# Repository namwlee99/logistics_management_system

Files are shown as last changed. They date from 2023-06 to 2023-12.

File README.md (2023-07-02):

# 물류관리 시스템
## 작품소개
이 작품은 물류관리 시스템으로, Raspberry Pi 프로세서를 기반으로 개발되었습니다. 시스템은 PI 카메라, 컨베이어 벨트, IR Sensor, Servo Motor 등을 효과적으로 활용하여 물류 작업을 자동화합니다. 또한 화재 감지 센서와 물 감지 센서를 통해 창고를 효율적으로 관리할 수 있습니다. LCD와 Buzzer를 사용하여 창고의 상태를 실시간으로 확인할 수 있습니다. 이 시스템은 물류 작업 환경에서 보다 효율적인 창고 관리를 지원하며, 사고나 이상 상황을 신속하게 감지하여 조치할 수 있도록 도와줍니다. 더욱 정확하고 안전한 물류 운영을 위해 다양한 기능을 통합하여 최적의 창고 관리 솔루션을 제공합니다.

## 팀구성
아이디어 제안 및 기획: **이남웅**   
하드웨어 설계 및 구현: 정승훈   
소프트웨어 개발: **이남웅**   
디자인: 정승훈   
시스템 통합 및 테스트: **이남웅**   

## 개발기간
2022/06/24 ~ 2022/09/28

## 사용한 부품
PI 카메라: QR 코드를 식별하여 인식할 수 있는 카메라입니다. 이를 통해 물류 작업에서 중요한 정보를 자동으로 인식하고 처리할 수 있습니다.

DHT11 센서: 창고의 온도와 습도를 측정하는 센서입니다. 스토리지의 적절한 환경을 유지하기 위해 사용됩니다.

Water Sensor: 물이 센서에 닿으면 작동하는 센서입니다. 누수나 수위 변화를 신속하게 감지하여 관련 문제를 예방하거나 조치할 수 있습니다.

Gas Sensor: 가스가 근처에 발생할 경우 작동하는 센서입니다. 유해 가스 누출을 신속하게 감지하여 안전에 기여합니다.

Flame Sensor: 불이 근처에 있을 경우 작동하는 센서입니다. 화재를 조기에 감지하고 경보를 울리거나 조치를 취할 수 있습니다.

Buzzer: 재난 감지 센서가 작동할 경우 경보를 발생시키는 소리 알림 장치입니다.

LCD2004: 스토리지의 적재량, 온습도 등의 정보를 표시하는 20x4 문자 LCD입니다. 또한 재난 상황 발생 시 경고 메시지를 표시하여 시각적으로 알릴 수 있습니다.

TT Motor: 컨베이어 벨트를 조작하기 위해 양 끝단에 설치된 모터입니다. 스토리지 내 물체를 분류하고 이동시키는 역할을 합니다.

MCP3008: 아날로그 신호를 디지털 신호로 변환해주는 ADC(Analog-to-Digital Converter) 칩입니다. Water Sensor와 같이 아날로그 입력을 받아서 Raspberry Pi가 처리할 수 있는 디지털 신호로 변환합니다.

IR Sensor: 컨베이어 벨트 위에 있는 물체를 감지하는 인프라레드(IR) 센서입니다. 물체의 존재를 신속하게 감지하여 작업 프로세스를 제어하거나 인식에 활용할 수 있습니다.

Servo Motor: 스토리지 내 물체를 분류하기 위해 사용되는 모터입니다. 스토리지 별로 물체를 이동시키거나 배치할 수 있습니다.   

## 동작방식
### PI 카메라를 통한 바코드 인식
1. PI 카메라는 제품에 있는 바코드를 인식하여 위치 정보를 가져옵니다. 이 정보를 기반으로 해당 제품이 위치한 컨베이어 벨트가 작동하게 됩니다. 만약 PI 카메라가 바코드를 인식하지 못할 경우 Buzzer가 작동하여 경고음을 울립니다.

2. IR 센서를 통한 위치 인식: 제품이 교차점에 도달하면 교차점에 있는 IR 센서가 제품의 위치를 감지하여 인식합니다. 이를 통해 제품을 이동시킬지 여부를 판별합니다.

3. 서브모터를 이용한 제품 이동: 해당 교차점에서 제품을 이동해야 할 경우, 서브모터가 작동하여 제품을 원하는 위치로 이동시킵니다. 이를 통해 제품의 효율적인 관리와 분류가 가능해집니다.

### 센서 내장 및 상태 확인
시스템은 Flame 센서, Gas 센서, Water 센서, 온습도 센서 등을 내장하여 제품의 안전 및 환경 상태를 모니터링합니다. LCD와 Buzzer를 통해 물류창고의 상태를 실시간으로 확인할 수 있습니다.

물류관리 시스템은 PI 카메라를 통해 바코드 인식과 위치 정보를 활용하고, IR 센서와 서브모터를 이용하여 제품의 이동을 제어합니다. 또한 센서를 통해 환경 및 안전 상태를 모니터링하며, LCD와 Buzzer를 통해 사용자에게 정보를 제공합니다.

## 블록도


## 회로도
KakaoTalk_Photo_2023-07-02-10-03-41

## 사진
KakaoTalk_Photo_2023-06-25-16-47-12

## 작동 동영상
Watch the video (https://youtu.be/YHekVKBjydo)

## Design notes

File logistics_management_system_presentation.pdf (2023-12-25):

# 종합설계작품계획서

# 학 번 | 이 름 20191629 | 정승훈 20191633 | 이남웅

# 작품명 : 물류관리 시스템 4차 발표

목차

# 1. 작품개요 2. 업무분담 3. 진행일정표 4. 동작설명서(블록도/순서도) 5. 회로도 6. 프로그램 소스코드 7. 작품 동작 영상 8. 작품 활용 방안

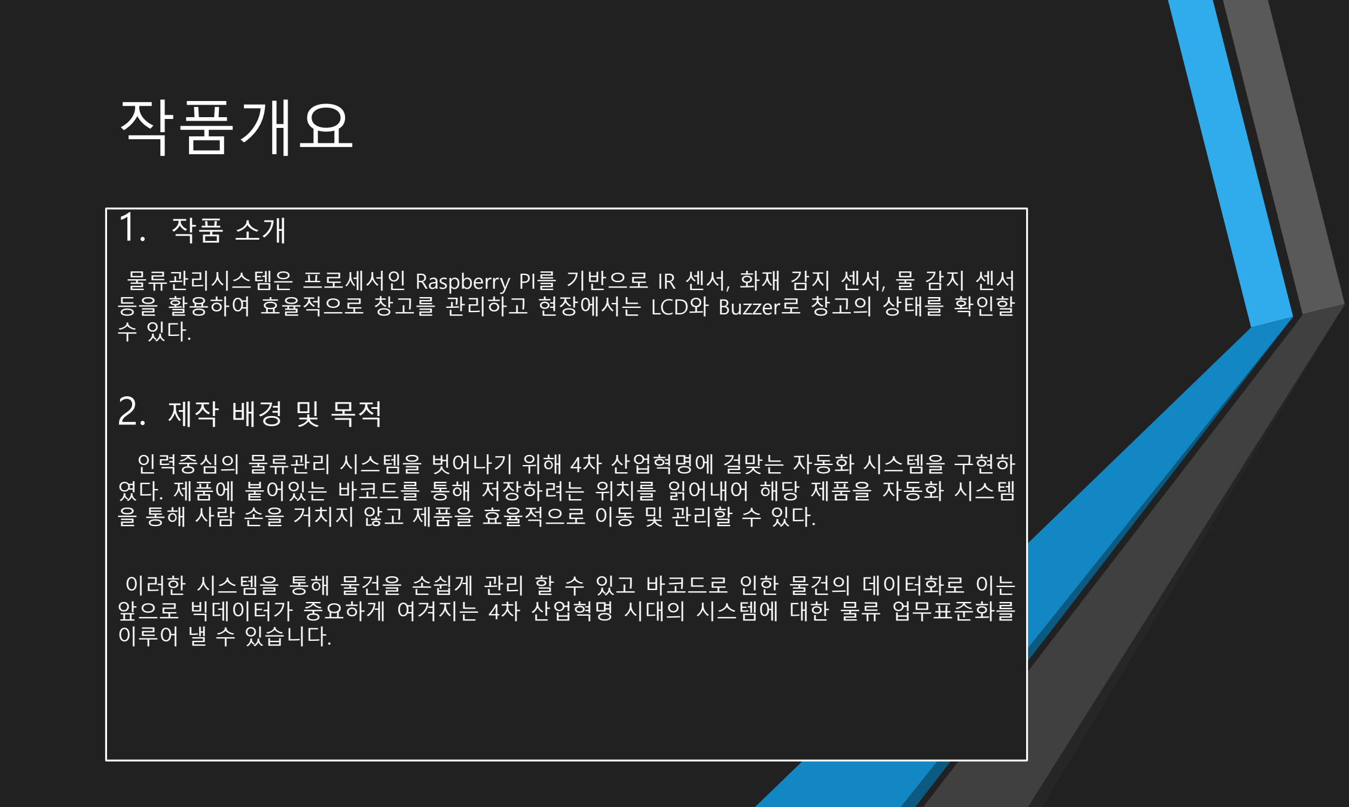
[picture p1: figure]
작품개요; 이루어 낼 수 있습니다.

# 물류관리시스템은 프로세서인 Raspberry PI를 기반으로 IR 센서, 화재 감지 센서, 물 감지 센서 등을 활용하여 효율적으로 창고를 관리하고 현장에서는 LCD와 Buzzer로 창고의 상태를 확인할

# 인력중심의 물류관리 시스템을 벗어나기 위해 4차 산업혁명에 걸맞는 자동화 시스템을 구현하 였다. 제품에 붙어있는 바코드를 통해 저장하려는 위치를 읽어내어 해당 제품을 자동화 시스템

을 통해 사람 손을 거치지 않고 제품을 효율적으로 이동 및 관리할 수 있다.

# 이러한 시스템을 통해 물건을 손쉽게 관리 할 수 있고 바코드로 인한 물건의 데이터화로 이는 앞으로 빅데이터가 중요하게 여겨지는 4차 산업혁명 시대의 시스템에 대한 물류 업무표준화를

# 업무 분담

업 무 | 담 당 자
자료수집 | 정승훈, 이남웅
도면작성 | 정승훈
자재구입 | 정승훈, 이남웅
PCB조립 | 정승훈
프로그램 작성 | 이남웅
기구부 제작 | 정승훈, 이남웅
작품연동검사 | 정승훈, 이남웅

H/W

# 정승훈

# 기구부

공동

S/W

# 이남웅

| 6 월 | 7 월 | 8 월 | 9 월
5 | 1 | 2 | 3 | 4 | 1 | 2 | 3 | 4 | 5 | 1 | 2
자료수집 | 계획
| 실적
하드웨어 구성 | 계획
| 실적
프로그래밍 | 계획
| 실적
기구물 제작 | 계획
| 실적
동작테스트 | 계획
| 실적
발표(1 차, 2 차, 3 차, 최 종 ) | 계획 | 1 차 | | | 2 차 | | | | | | 3 차 | 4 차 | 최종
| 실적
최종보고서 | 계획
| 실적
계획 | 실적

# 진행일정표

# 동작설명서

# - 물류관리 시스템은 Pi 카메라를 통해 제품에 있는 바코드를 읽어

위치정보를 불러들여 제품이 있는 컨베이어 벨트가 작동하게 되고,

# 제품이 교차점에 도달하게 되면 교차점에 있는 IR 센서가 제품 위치 를 인식하게 되고 제품을 이동시킬지 판별한다. Pi 카메라에서 바코

드 인식을 못할 경우 Buzzer가 작동하여 경적음을 울린다.

# - 만약 해당 교차점에서 이동하려고 하면 서브모터가 제품을 이동시 키게 되고, 컨베이어 벨트에서 지정된 위치로 이동시키게 된다. 제품 의 효율적 관리를 위해 Flame 센서와 Gas 센서, Water 센서, 온습도 센서를 내장하게 되고 LCD 와 Buzzer를 통해 물류창고 상태를 확인

할 수 있다.

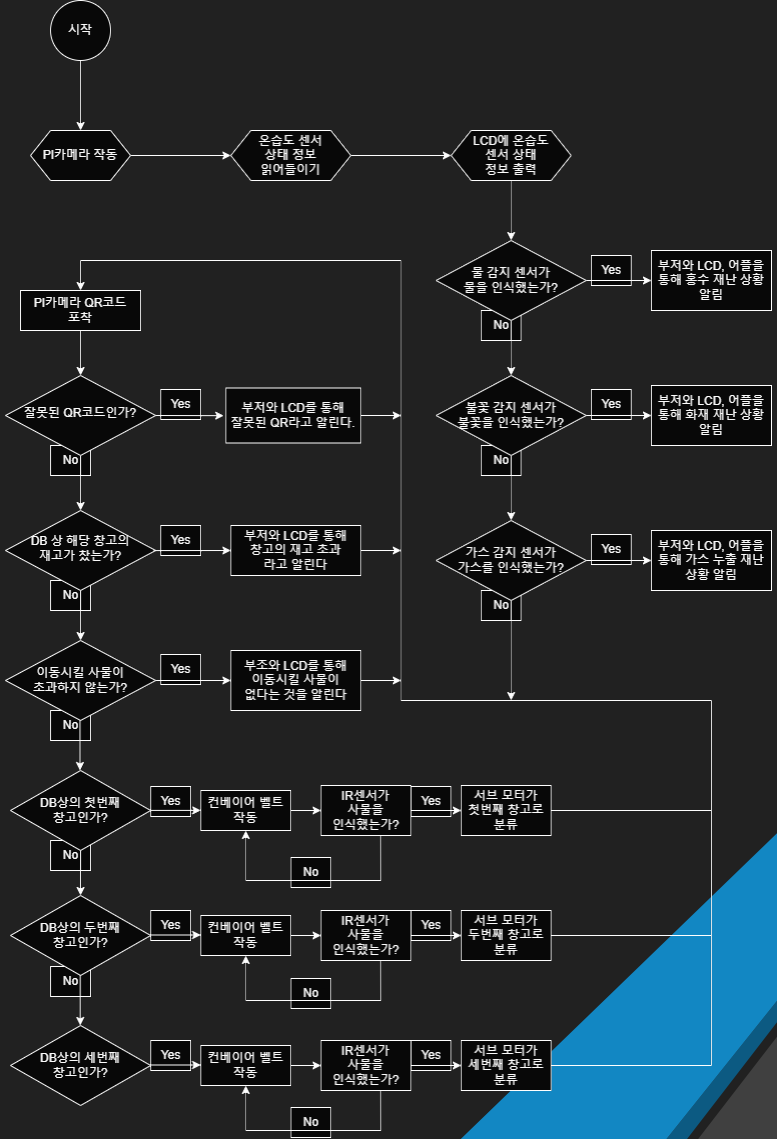
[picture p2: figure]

# 동작설명서

# - 순서도

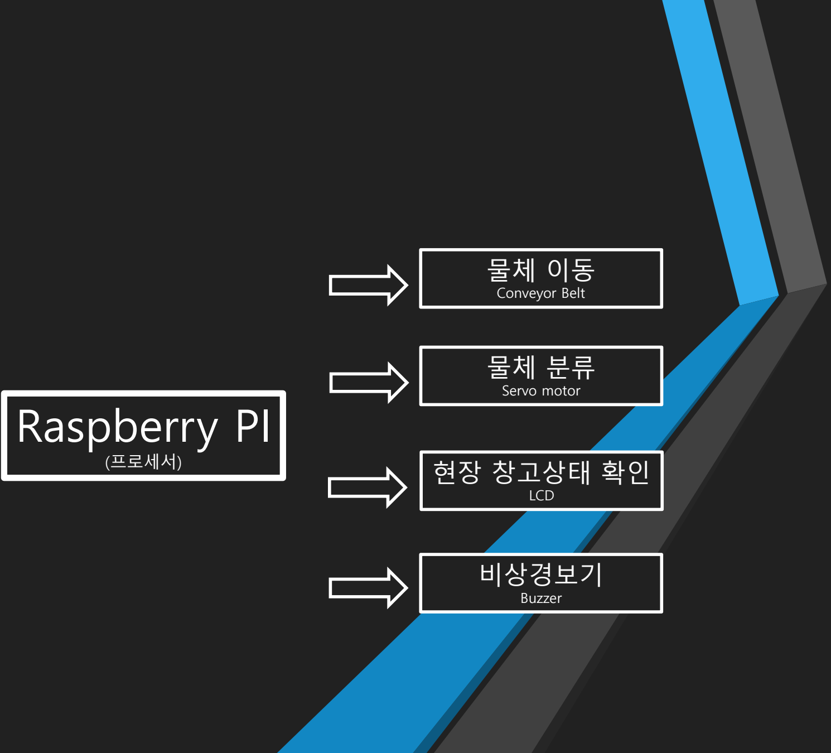
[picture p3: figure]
Conveyor Belt; Servo motor; 현장 창고상태 확인; LCD; 비상경보기; Buzzer; Raspberry PI; (프로세서)

# 동작설명서

# - 블록도

# 파이 카메라

## (바코드 인식)

# IR 센서

## (물체 인식)

# Flame 센서

## (화재감지기)

# Water 센서

## (침수감지기)

# DHT 11

## (온습도 감지기)

# 회로도

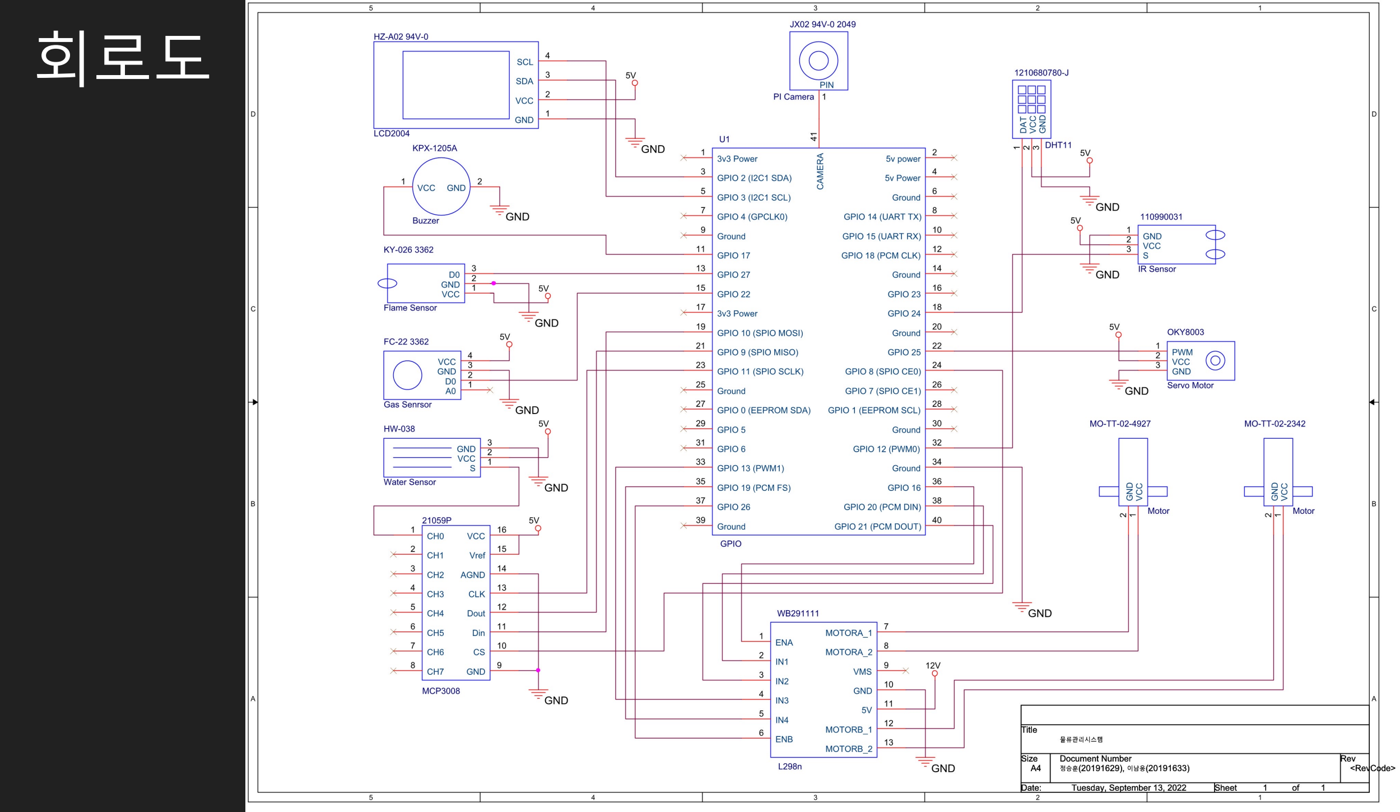
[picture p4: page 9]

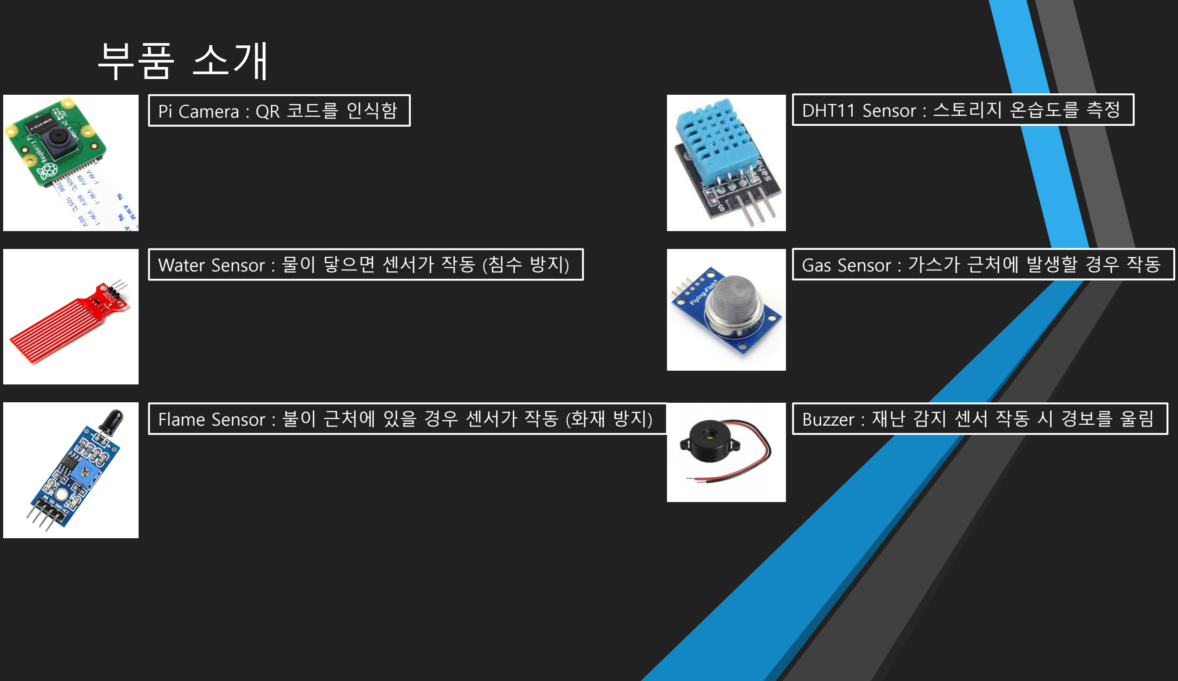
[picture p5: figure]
Pi Camera : QR 코드를 인식함; Water Sensor : 물이 닿으면 센서가 작동 (침수 방지); DHT11 Sensor : 스토리지 온습도를 측정; Gas Sensor : 가스가 근처에 발생할 경우 작동; Buzzer : 재난 감지 센서 작동 시 경보를 울림

# Flame Sensor : 불이 근처에 있을 경우 센서가 작동 (화재 방지)

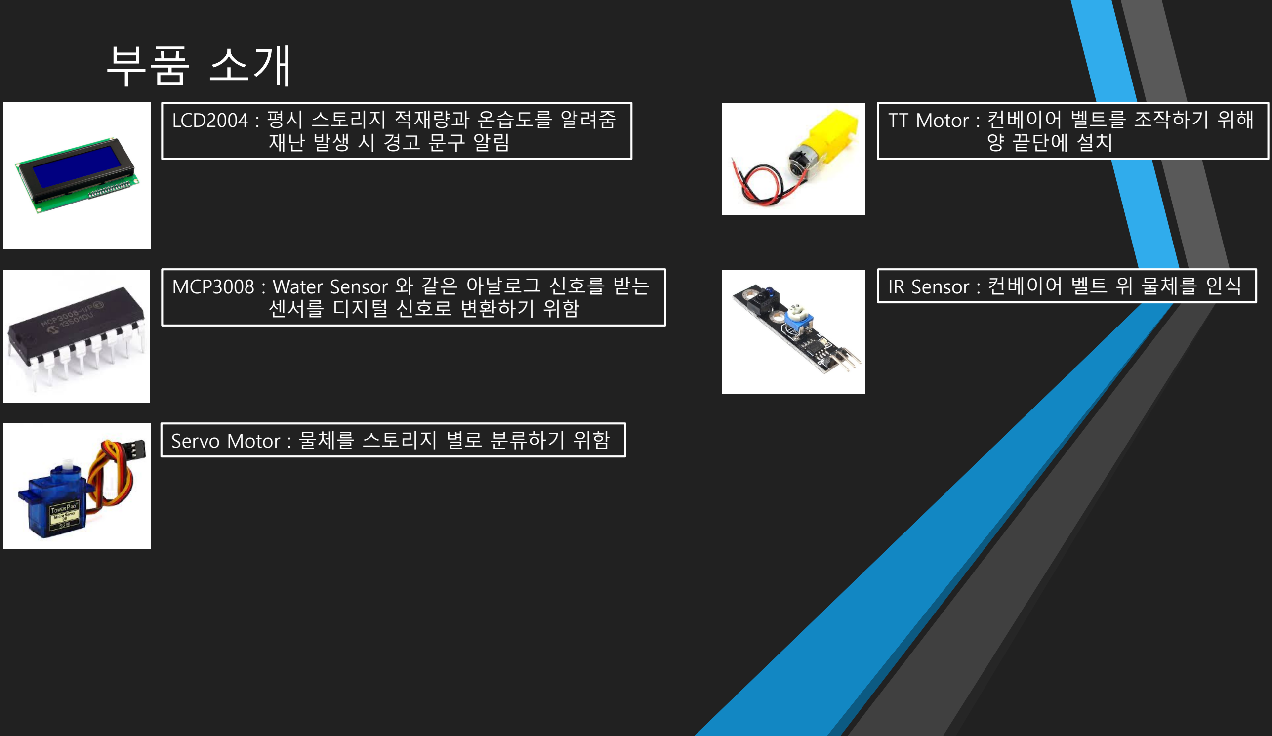
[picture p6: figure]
LCD2004 : 평시 스토리지 적재량과 온습도를 알려줌 재난 발생 시 경고 문구 알림; MCP3008 : Water Sensor 와 같은 아날로그 신호를 받는 센서를 디지털 신호로 변환하기 위함; Servo Motor : 물체를 스토리지 별로 분류하기 위함; TT Motor : 컨베이어 벨트를 조작하기 위해 양 끝단에 설치; IR Sensor : 컨베이어 벨트 위 물체를 인식

# 시작 코드

try: | #오류가 있어도 실행
motor_stop() | #motor 초기화
main_p=Process(target=main()) | #멀티프로세스 메인 함수 선언
main_p.start() | #멀티프로레스 메인 함수 시작
except KeyboardInterrupt: | #만약 ctrl+c로 종료할 경우
GPIO.cleanup() | #GPIO 초기화
cv2.destroyAllWindows() | #모든 창 닫기
lcd.clear() | #lcd 초기화
spi.close() | #spi 초기화
print("--------------------------------------------------\nSystem Shutdown\n--------------------------------------------------") | #종료 상태 출력
sys.exit(0) | #시스템 종료

# 메인 코드_(바코드 인식 코드)

def main(): | #메인 함수 선언
motor_state = 0 | #motor 초기화
while(cap.isOpened()): | #Pi카메라가 작동하는 한 무한반복
ret, img = cap.read() | #Pi카메라 값 불러오기
if not ret: | #만약 ret값이 없는 경우
continue | #그래도 계속 진행
gray = cv2.cvtColor(img, cv2.COLOR_BGR2GRAY) | #회색 상태로 바코드 읽기
decoded = pyzbar.decode(gray) | #회색으로 디코드
flood_state = (flood() > 100) | #water sensor 값이 100인 경우 참 아닌 경우 거짓
flame_state = GPIO.input(flame_pin) | #flame sensor 상태 저장
gas_state = GPIO.input(gas_pin) | #gas sensor 상태 저장
state_check_p=Process(target=state_check(0, 0, flood_state, flame_state, gas_state))
#멀티프로세스 시작할 상태 확인 함수 지정

state_check_p.start() | #멀티프로세스 상태 확인 함수 시작
motor_action_p=Process(target=motor_action(motor_state)) #멀티프로세스 모터 작동 함수 지정
motor_action_p.start() | #멀티프로세스 모터 작동 함수 시작
for d in decoded: | #디코드
x, y, w, h = d.rect | #x, y, w, h 값 지정
if not((flood_state)) and flame_state and gas_state: | #재난 상태가 아닌 경우
if (d.data.decode('utf-8') == object_list[0]) and (object_num[1] < 3) and (object_num[0] <
5): | #만약 첫번째 창고 QR코드인 경우
object_num[1] += 1 | #첫번째 창고 재고 추가
iden_obj = int(d.data.decode('utf-8’)) | #임시 사물 상태 저장
print_text = ' First Storage ‘ | #출력 메세지 저장
object_num[0] = object_num[1] + object_num[2] + object_num[3]
#모든 창고 재고 계산

state_check_p=Process(target=state_check(1, print_text, 0, 1, 1))
#멀티프로세스 상태 확인 함수 선언

state_check_p.start() | #멀티프로세스 상태 확인 함수 시작
motor_state = 1 | #모터 작동
cap.release() | #카메라 초기화
time.sleep(1.5) | #1.5초간 딜레이
cap.open(0) | #카메라 시작
elif (d.data.decode('utf-8') == object_list[1]) and (object_num[2] < 3) and (object_num[0] <
5): | #만약 두번째 창고 QR코드인 경우
object_num[2] += 1 | #두번재 창고 재고 추가
iden_obj = int(d.data.decode('utf-8’)) | #임시 사물 상태 저장
print_text = ' Second Storage ‘ | #출력 메세지 저장

object_num[0] = object_num[1] + object_num[2] + object_num[3] #모든 창고 재고 계산
state_check_p=Process(target=state_check(1, print_text, 0, 1, 1))
#멀티프로세스 상태 확인 함수 선언

state_check_p.start() | #멀티프로세스 상태 확인 함수 시작
motor_state = 1 | #모터 작동
cap.release() | #카메라 초기화
time.sleep(1.5) | #1.5초간 딜레이
cap.open(0) | #카메라 시작
elif (d.data.decode('utf-8') == object_list[2]) and (object_num[3] < 3) and (object_num[0] <
5): | #만약 세번째 창고 QR코드인 경우
object_num[3] += 1 | #세번째 창고 재고 추가
iden_obj = int(d.data.decode('utf-8’)) | #임시 사물 상태 저장
print_text = ' Third Storage ‘ | #출력 메세지 저장
object_num[0] = object_num[1] + object_num[2] + object_num[3]
| #모든 창고 재고 계산
state_check_p=Process(target=state_check(1, print_text, 0, 1, 1))
| #멀티프로세스 상태 확인 함수 선언
state_check_p.start() | #멀티프로세스 상태 확인 함수 시작
motor_state = 1 | #모터 작동
cap.release() | #카메라 초기화
time.sleep(1.5) | #1.5초간 딜레이
cap.open(0) | #카메라 시작
elif ((d.data.decode('utf-8') == object_list[0]) or (d.data.decode('utf-8') == object_list[1]) or (d.data.decode('utf-8') == object_list[2])) and \
(object_num[0] == 5): | #만약 사물이 초과된 경우
print_text = ' Object Over ‘ | #출력 메세지 저장
object_num[0] = object_num[1] + object_num[2] + object_num[3]
| #모든 창고 재고 계산
state_check_p=Process(target=state_check(2, print_text, 0, 1, 1))
| #멀티프로세스 상태 확인 함수 선언
state_check_p.start() | #멀티프로세스 상태 확인 함수 시작
cap.release() | #카메라 초기화
time.sleep(1.5) | #1.5초간 딜레이
cap.open(0) | #카메라 시작

elif ((d.data.decode('utf-8') == object_list[0]) or (d.data.decode('utf-8') == object_list[1]) or (d.data.decode('utf-8') == object_list[2])) and \
((object_num[1] == 3) or (object_num[2] == 3) or (object_num[3] == 3)):
#만약 창고에 사물이 가득 찬 경우

print_text = ' Storage is full ‘ | #출력 메세지 저장
object_num[0] = object_num[1] + object_num[2] + object_num[3]
| #모든 창고 재고 계산
state_check_p=Process(target=state_check(2, print_text, 0, 1, 1))
| #멀티프로세스 상태 확인 함수 선언
state_check_p.start() | #멀티프로세스 상태 확인 함수 시작
cap.release() | #카메라 초기화
time.sleep(1.5) | #1.5초간 딜레이
cap.open(0) | #카메라 시작
else: | #만약 잘못된 바코드인 경우
print_text = ' Wrong QR code ‘ | #출력 메세지 저장
object_num[0] = object_num[1] + object_num[2] + object_num[3]
| #모든 창고 재고 계산
state_check_p=Process(target=state_check(2, print_text, 0, 1, 1))
| #멀티프로세스 상태 확인 함수 선언
state_check_p.start() | #멀티프로세스 상태 확인 함수 시작
cap.release() | #카메라 초기화
time.sleep(1.5) | #1.5초간 딜레이
cap.open(0) | #카메라 시작

# 상태 체크 코드_(재난 상황, 재고 관리)

def state_check(state_mode, print_text, flood_state, flame_state, gas_state): | #상태 체크 함수 선언
global dht11, dht11_state, motor_state | #전역변수 dht11, dht11 상태, motor 상태 선언
if flood_state and flame_state and gas_state: | #만약 홍수 상태인 경우
crisis_string[1] = '###### FLOOD #######’ | #2번째 줄 홍수 상태 저장
crisis_string[2] = '##### OUTBREAK #####’ | #3번째 줄 홍수 상태 저장
elif (not(flood_state)) and (not(flame_state)) and gas_state: | #만약 불꽃 발생 상태인 경우
crisis_string[1] = '###### FLAME #######’ | #2번째 줄 불꽃 발생 저장
crisis_string[2] = '##### OUTBREAK #####’ | #3번째 줄 불꽃 발생 저장
elif (not(flood_state)) and flame_state and (not(gas_state)): | #만약 가스 누출 발생 상태인 경우
crisis_string[1] = '####### GAS ########’ | #2번째 줄 가스 누출 발생 저장
crisis_string[2] = '####### LEAK #######’ | #3번째 줄 가스 누출 발생 저장
elif flood_state and (not(flame_state)) and gas_state: | #만약 홍수, 불꽃 발생 상태인 경우
crisis_string[1] = '### FLOOD FLAME ####’ | #2번째 줄 홍수, 불꽃 발생 저장
crisis_string[2] = '##### OUTBREAK #####’ | #3번째 줄 홍수, 불꽃 발생 저장
elif flood_state and flame_state and (not(gas_state)): | #만약 홍수, 가스 누출 상태인 경우
crisis_string[1] = '## FLOOD OUTBREAK ##’ | #2번째 줄 홍수, 가스 누출 발생 저장
crisis_string[2] = '##### GAS LEAK #####’ | #3번째 줄 홍수, 가스 누출 발생 저장
elif (not(flood_state)) and (not(flame_state)) and (not(gas_state)): | #만약 불꽃 발생, 가스 누출인 경우
crisis_string[1] = '## FLAME OUTBREAK ##’ | #2번째 줄 불꽃 발생, 가스 누출 저장
crisis_string[2] = '##### GAS LEAK #####’ | #3번째 줄 불꽃 발생, 가스 누출 저장
elif flood_state and (not(flame_state)) and (not(gas_state)): | #만약 모든 재난 상태인 경우
crisis_string[1] = 'FLOOD FLAME OUTBREAK’ | #2번째 줄 모든 재난 저장
crisis_string[2] = '##### GAS LEAK #####’ | #3번째 줄 모든 재난 저장
else: | #재난 상태가 아니인 경우
if state_mode == 0 and (dht11.is_valid() and ((dht11_state[0] != dht11.temperature) or (dht11_state[1]
!= dht11.humidity))): | #만약 온습도가 갱신될 때
crisis_string[0] = ' Camera is Ready ‘ | #1번째 줄 카메라 준비 상태 저장
crisis_string[1] = '1st St: %d 2st St: %d ' %(object_num[1], object_num[2])
| #2번째 줄 1, 2번째 재고 상태 저장
crisis_string[2] = '3st St: %d All St: %d ' %(object_num[3], object_num[0])
| #2번째 줄 3, 4번째 재고 상태 저장
crisis_string[3] = 'Tem: %-3.1f°C Hum: %d%%' % (dht11.temperature, dht11.humidity)
| #4번째 줄 온습도 상태 저장
dht11_state[0] = dht11.temperature | #dht11 온도 저장
dht11_state[1] = dht11.humidity | #dht11 습도 저장
state_print(state_mode, crisis_string) | #상태 출력
elif state_mode == 0 and crisis_string[0] != ' Camera is Ready ‘: | #만약 창고 재고가 변경될 때
crisis_string[0] = ' Camera is Ready ‘ | #1번째 줄 카메라 준비 상태 저장

crisis_string[1] = '1st St: %d 2st St: %d ' %(object_num[1], object_num[2]) #2번째 줄 1, 2번째 재고 상태 저장
crisis_string[2] = '3st St: %d All St: %d ' %(object_num[3], object_num[0])
#3번째 줄 3, 4번째 재고 상태 저장

crisis_string[3] = 'Tem: %-3.1f°C Hum: %d%%' % (dht11.temperature, dht11.humidity)
#4번째 줄 온습도 상태 저장

dht11_state[0] = dht11.temperature | #dht11 온도 저장
dht11_state[1] = dht11.humidity | #dht 습도 저장
state_print(state_mode, crisis_string) | #상태 출력
elif state_mode > 0: | #만약 QR코드가 인식 되었을 때
crisis_string[0] = str(print_text) | #인식된 QR코드 상태 저장
crisis_string[1] = '1st St: %d 2st St: %d ' %(object_num[1], object_num[2])
| #2번째 줄 1, 2번째 재고 상태 저장
crisis_string[2] = '3st St: %d All St: %d ' %(object_num[3], object_num[0])
| #3번째 줄 3, 4번째 재고 상태 저장
if dht11.is_valid() and ((dht11_state[0] != dht11.temperature) or (dht11_state[1] != dht11.humidity)):
| #만약 온습도가 갱신될 때
crisis_string[3] = 'Tem: %-3.1f°C Hum: %d%%' % (dht11.temperature, dht11.humidity)
| #4번째 줄 온습도 상태 저장
dht11_state[0] = dht11.temperature | #dht11 온도 저장
dht11_state[1] = dht11.humidity | #dht11 습도 저장
state_print(state_mode, crisis_string) | #상태 출력
buzzer(state_mode) | #buzzer 작동
if flood_state or (not(flame_state)) or (not(gas_state)): | #만약 재난 상태일 경우
crisis_string[0] = '########## WARNING #’ | #1번째 줄 경고 상태 저장
crisis_string[3] = '# WARNING ##########’ | #4번째 줄 경고 상태 저장
state_print(5, crisis_string) | #상태 출력
buzzer(3) | #buzzer를 3번 울림
crisis_string[0] = '# WARNING ##########’ | #1번째 줄 경고 상태 저장
crisis_string[3] = '########## WARNING #’ | #4번째 줄 경고 상태 저장
state_print(5, crisis_string) | #상태 출력
dht11 = dht11_pin.read() | #dht11에서 온습도 읽기
time.sleep(0.25) | #0.25초간 딜레이

# 상태 출력 코드_(파이썬 출력, LCD)

def state_print(state_mode, crisis_string): | #상태 출력 함수 선언
global dht11, dht11_state | #전연변수 dht11, dht11 상태 선언
print("--------------------------------------------------") | #출력창 구분
print("%s\n%s\n%s\n%s" % (crisis_string[0], crisis_string[1], crisis_string[2], crisis_string[3]))
| #저장된 각 줄의 값 출력
if state_mode < 3: | #재난 상태가 아닌 경우
for i in range(0, 2): | #lcd 1, 2번째 출력
lcd.setCursor(0,i) | #lcd 1, 2번째 줄 커서 설정
lcd.print(crisis_string[i]) | #lcd 1, 2번째 줄 출력
for i in range(2, 3): | #lcd 3, 4번째 출력
lcd.setCursor(4,i) | #lcd 3, 4번째 줄 커서 설정
lcd.print(crisis_string[i]) | #lcd 3, 4번째 줄 출력
lcd.setCursor(4,3) | #lcd 4번째 줄 커서 설정
lcd.print("Tem: %-3.1f" % dht11_state[0]) | #lcd상 온도 출력
lcd.createChar(0, lcd_celsius_symbol) | #lcd상 온도 섭씨 기호 출력
lcd.setCursor(13,3) | #lcd 4번째 줄 커서 설정
lcd.write(0) | #lcd 값 출력
lcd.setCursor(14,3) | #lcd 4번째 줄 커서 설정
lcd.print("C Hum: %d%%" % dht11_state[1]) | #lcd상 습도 출력
else: | #재난 상태인 경우
for i in range(0, 2): | #lcd 1, 2번째 출력
lcd.setCursor(0,i) | #lcd 1, 2번째 줄 커서 설정
lcd.print(crisis_string[i]) | #lcd 1, 2번째 줄 출력
for i in range(2, 4): | #lcd 3, 4번째 출력
lcd.setCursor(4,i) | #lcd 3, 4번째 줄 커서 설정
lcd.print(crisis_string[i]) | #lcd 3, 4번째 줄 출력

# 기타 함수 코드

def motor_start(): | #motor 시작 함수 선언
pwm1.ChangeDutyCycle(100) | #motor1 속도 지정
pwm2.ChangeDutyCycle(100) | #motor2 속도 지정
GPIO.output(motor1_pin[1], True) | #motor1 직진

## GPIO.output(motor1_pin[2], False)

GPIO.output(motor2_pin[0], True) | #motor2 직진

## GPIO.output(motor2_pin[1], False)

def motor_stop(): | #motor 정지 함수 선언
pwm1.ChangeDutyCycle(0) | #motor1 속도 지정
pwm2.ChangeDutyCycle(0) | #motor2 속도 지정
def first_servo(): | #첫번째 창고 이동을 위한 서브모터 동작 함수 선언
servo.ChangeDutyCycle(6.85) | #서브모터 조정
time.sleep(3) | #3초간 딜레이
def second_servo(): | #두번째 창고 이동을 위한 서브모터 동작 함수 선언
servo.ChangeDutyCycle(4.9) | #서브모터 조정
time.sleep(3) | #3초간 딜레이
def third_servo(): | #세번째 창고 이동을 위한 서브모터 동작 함수 선언
servo.ChangeDutyCycle(3.0) | #서브모터 조정
time.sleep(3) | #3초간 딜레이
def buzzer(buzzer_num): | #buzzer 작동 함수 선언
for i in range(0, buzzer_num): | #buzzer를 몇번 울릴지에 따른 반복문
GPIO.output(buzzer_pin, True) | #buzzer 울림
time.sleep(0.0625) | #0.0625초간 딜레이
GPIO.output(buzzer_pin, False) | #buzzer 정지
time.sleep(0.0625) | #0.0625초간 딜레이
def flood(): | #water sensor 작동을 위한 함수 선언
assert 0 <= spi_channel <= 0 | #water sensor spi chnnel 설정
if spi_channel: | #water sensor가 spi channel일 경우
cbyte = 0b11000000 | #0b110000000로 세팅
else: | #water sensor가 spi channel이 아닌 경우
cbyte = 0b10000000 | #0b10000000 로 세팅
r = spi.xfer2([1, cbyte, 0]) | #spi channel 값 받기
return ((r[1] & 31) << 6) + (r[2] >> 2) | #수위에 따른 water sensor 값 반환

# 변수 선언 및 세팅값 설정 코드

### import sys, time, RPi.GPIO as GPIO, cv2, pyzbar.pyzbar as pyzbar, dht11, spidev from multiprocessing import Process from RPi_I2C_LCD_driver import RPi_I2C_driver

GPIO.setmode(GPIO.BCM) | #GPIO BCM 핀 번호 설정
GPIO.setwarnings(False) | #GPIO 오류 알림 끄기
GPIO.cleanup() | #GPIO 초기화
cap = cv2.VideoCapture(0) | #Pi카메라 포트 설정
motor1_pin = (16, 20, 21) | #motor1 핀 설정
motor2_pin = (13, 19, 26) | #motor2 핀 설정
GPIO.setup(motor1_pin, GPIO.OUT) | #GPIO motor1 세팅 설정
GPIO.setup(motor2_pin, GPIO.OUT) | #GPIO motor2 세팅 설정
pwm1 = GPIO.PWM(motor1_pin[0], 50) | #GPIO motor1 pwm 세팅
pwm2 = GPIO.PWM(motor2_pin[2], 50) | #GPIO motor2 pwm 세팅
pwm1.start(50) | #motor1 pwm 시작
pwm2.start(50) | #motor2 pwm 시작
motor_spe, motor_dur = 0, 0 | #motor 스피드, 지속시간 변수 선언
motor_state = 0 | #motor 상태 변수 선언
servo_pin = (25) | #servo motor 핀 설정
GPIO.setup(servo_pin, GPIO.OUT) | #GPIO servo motor 세팅 설정
servo = GPIO.PWM(servo_pin, 50) | #GPIO servo motor pwm 세팅
servo.start(0) | #servo motor 시작
ir_pin = (12) | #ir sensor 핀 설정
GPIO.setup(ir_pin, GPIO.IN) | #GPIO ir sensor 세팅 설정
ir_sta = 0 | #ir sensor 상태 변수 선언
buzzer_pin = (17) | #buzzer 핀 설정
GPIO.setup(buzzer_pin, GPIO.OUT) | #GPIO buzzer 세팅 설정
GPIO.output(buzzer_pin, False) | #buzzer 초기화
lcd = RPi_I2C_driver.lcd(0x27) | #lcd i2c 주소 설정
lcd.clear() | #lcd 초기화

lcd_celsius_symbol = (0b00111, 0b00101, 0b00111, 0b00000, 0b00000, 0b00000, 0b00000, 0b00000)

### #섭씨 이모티콘 변수 선언

crisis_string = ['', '', '', ‘’] | #lcd 4줄 리스트 선언
state_temp = 0 | #임시 상태 변수 선언
dht11_pin = dht11.DHT11(pin = 18) | #dht11 핀 설정
dht11 = dht11_pin.read() | #dht11 읽어들이는 변수 선언
dht11_state = [0, 0] | #dht11 온습도 변수 선언
spi = spidev.SpiDev() | #water sensor spi 객체 선언
spi.open(0, 0) | #water sensor 신호선 설정
spi.max_speed_hz = 250000 | #water sensor 최대 주파수 설정
spi_channel = (0) | #water sensor spi 채널 설정
flood_state = ‘’ | #water sensor 상태 변수 선언
flame_pin = (27) | #flame sensor 핀 설정
GPIO.setup(flame_pin, GPIO.IN) | #GPIO flame sensor 세팅 설정
flame_state = 0 | #flame sensor 상태 변수 선언
gas_pin = (22) | #gas sensor 핀 설정
GPIO.setup(gas_pin, GPIO.IN) | #GPIO gas sensor 세팅 설정
gas_state = 0 | #gas sensor 상태 변수 선언
object_list = ('1001', '1002', '1003’) | #QR코드값 창고 3개 지정
object_num = [0, 0, 0, 0] | #모든 사물값, 첫번째 창고, 두번째 창고, 세번째 창고 개수 변수 선언
iden_obj = 0 | #임시 사물 상태 변수 선언
object_order = [] | #사물 순서 리스트 선언
print_text = ‘’ | #출력 메세지 변수 선언

# 작품 동작 영상

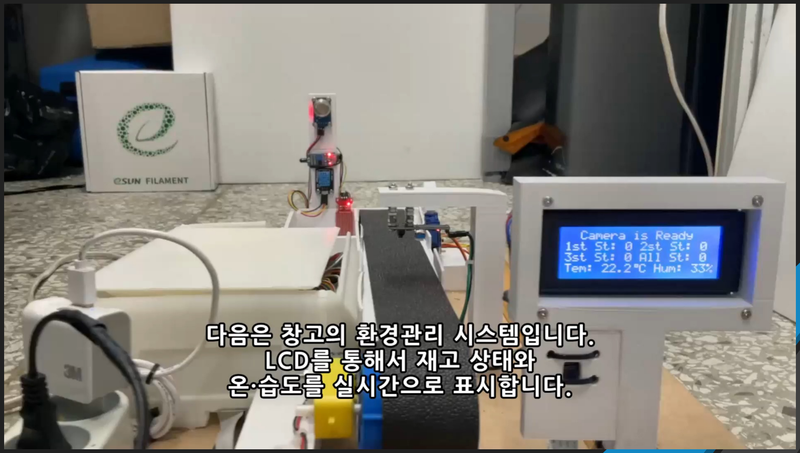
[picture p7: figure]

# 작품 동작 영상

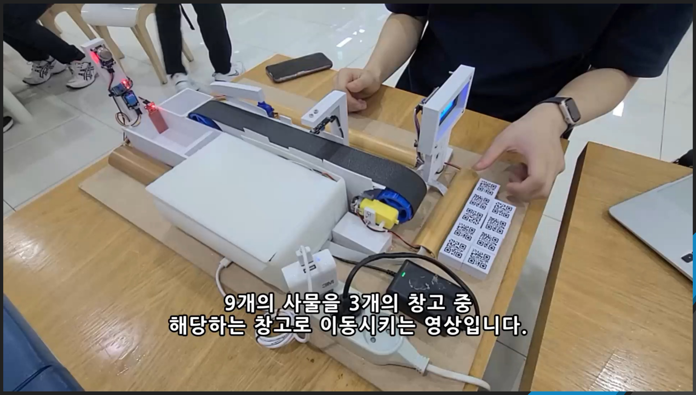
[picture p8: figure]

# 활용방안

# - 4차 산업혁명에 맞춰서 인력중심의 물류관리 시스템에서 벗어나 적 은 인력으로도 효율적인 물류관리 시스템을 구축할 수 있고, LCD나 Buzzer를 통해서 재고관리 뿐만 아니라 재난위기 상황을 확인할 수

있고 온습도에 민감한 제품까지도 효율적으로 관리 할 수 있다.

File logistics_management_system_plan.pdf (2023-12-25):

# 종합설계작품계획서

## 작 품 명 : 물류관리 시스템

구 분 | 내 용
담당교수 | 김 장 욱
소 속 | 정보전자공학과
조 원 | 정승훈 | 이남웅
학 번 | 20191629 | 20191633

### 1. 작품명

⇒ 물류관리 시스템

### 2. 조원 명단 및 업무 분담계획

- 조원명단

정 승 훈(20191629)
이 남 웅(20191633)
- 업무분담 계획
(2 | , | , | ) 명중 한명은 하드웨어 한명은 소프트웨어 담당 기구부는 같이
1) | : | , 자료수집 정승훈 이남웅
2) : 도면작성 정승훈
3) | : | , 자재구입 정승훈 이남웅
4) PCB | : 조립 정승훈
5) : 프로그램 작성 이남웅
6) | : | , 기구부 제작 정승훈 이남웅
7) | : | , 작품연동검사 정승훈 이남웅

### 3. 작품개요

- 작품설명
인력 중심의 물류관리 시스템을 벗어나 4차산업혁명에 걸맞은 자동화 시스템을 구현하였다 제품에 . 붙어있는 바코드를 통해 저장하려는 위치를 읽어내고 해당 제품을 자동화 시스템을 통해 사람 손을 거치지 않고 제품을 효율적으로 관리할 수 있다.
- 작품 구현 방법
PI 카메라를 통해 제품에 있는 바코드를 읽어 위치정보를 불러들여 제품이 있는 컨베이어 벨트가 작동하게 되고 제품이 , 교차점에 도달하게 되면 교차점에 있는 IR센서가 제품 위치를
인식하게 되고 제품을 이동시킬지 판별한다 | 카메라에서 . PI
바코드 인식을 못할 경우 Buzzer | . 가 작동하여 경적음을 울린다
만약 해당 교차점에서 이동하려고 하면 서보모터가 제품을
이동시키게 되고 컨베이어 , | 벨트에서 지정된 위치로 이동시키게
된다 제품의 . | Flame | Gas | , 효율적 관리를 위해 | 센서와 | 센서
Water | , | LCD Buzzer 센서 온습도 센서를 내장하게 되고 | 와 | 를
통해 물류창고 상태를 확인할 수 있다.

### 4. 일정표

일 자 구 분 | 4월 | 5월 | 6월
1 주차 | 2 주차 | 3 주차 | 4 주차 | 1 주차 | 2 주차 | 3 주차 | 4 주차 | 1 주차 | 2 주차 | 3 주차

자료수집

하드웨어 구성 / / 회로 자재구 입

소프트웨어 구 현

기구물 제작

작품연동테스트 ( ) 동작테스트

발표 차 차 (1 ,2 , 3, ) 차 최종

최종보고서

### 5. 블록도

- 블록 다이어그램

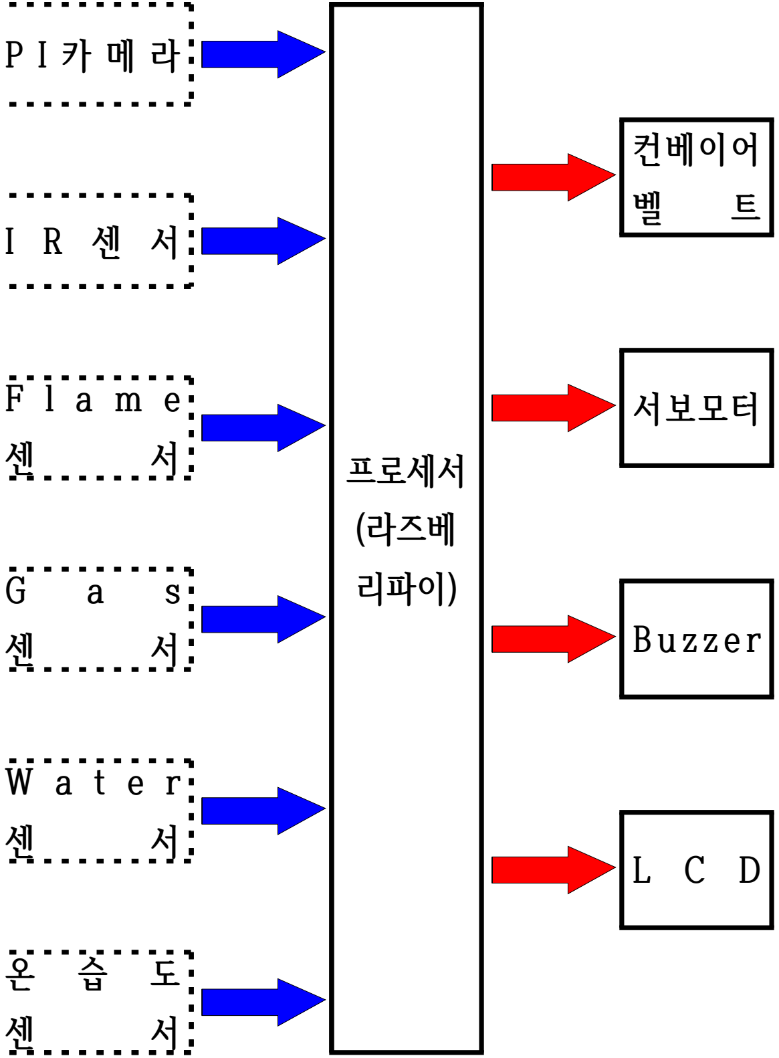
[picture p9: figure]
PI 카메라; 프로세서 (라즈베 리파이); 컨베이어; Flame; 서보모터; Buzzer; Water; LCD; 온습도

### 6. 활용방안

- 4차 산업혁명에 맞춰서 인력 중심의 물류관리 시스템에서 벗어나 적은 인력으로도 효율적인
물류관리 시스템을 구출할 수 있고 나 , LCD Buzzer를 통해서 재고관리뿐만 아니라 재난 위기 상황을 확인할 수 있고 온습도에 민감한 제품까지도 효율적으로 관리 할 수 있다.

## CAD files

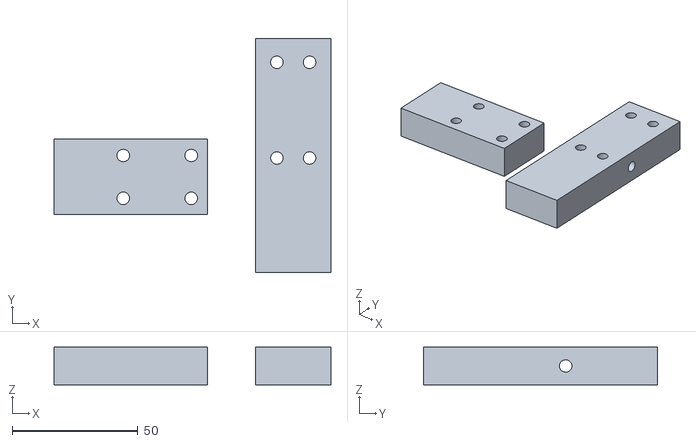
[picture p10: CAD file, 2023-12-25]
logistics_management_system_3d_printer_designs/sensor_stand.stl
110.0 x 93.0 x 15.0

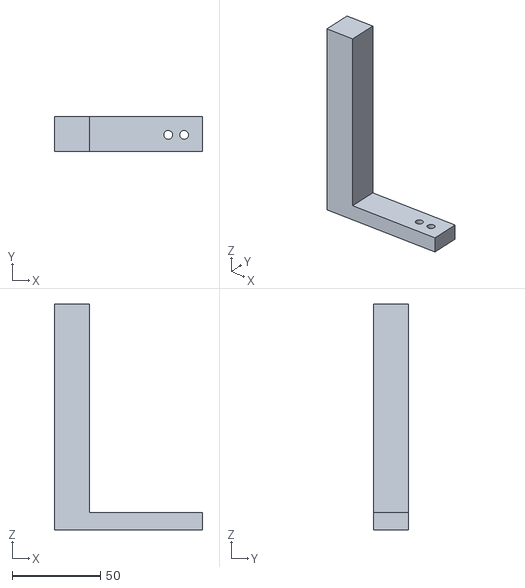
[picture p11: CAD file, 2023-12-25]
logistics_management_system_3d_printer_designs/ir_sensor_stand.stl
84.0 x 20.0 x 128.0

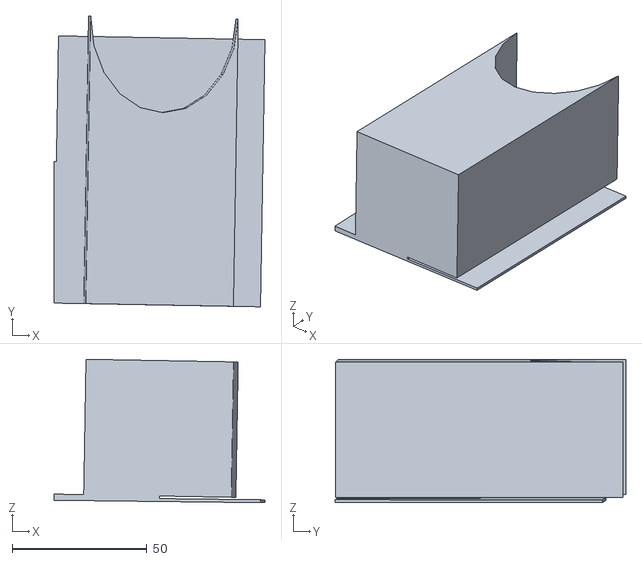
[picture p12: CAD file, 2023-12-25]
logistics_management_system_3d_printer_designs/conveyor_belt_1.stl
78.2 x 107.8 x 53.2

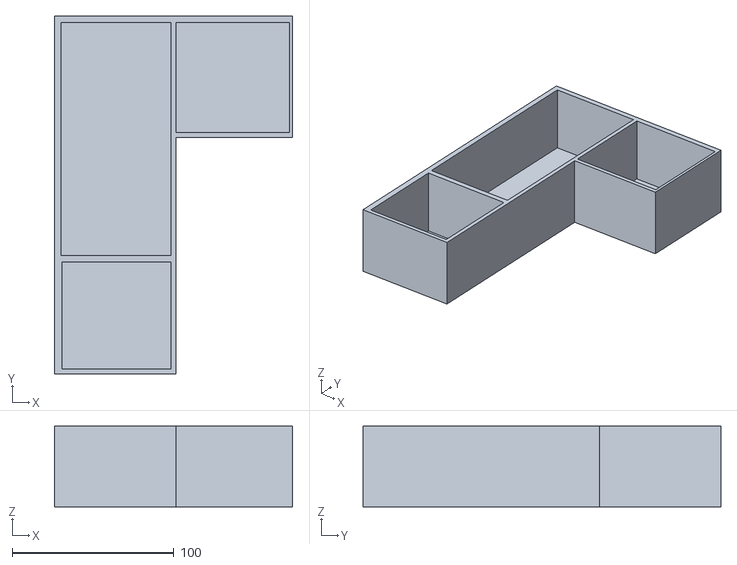
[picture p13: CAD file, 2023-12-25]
logistics_management_system_3d_printer_designs/storage_unit.stl
147.0 x 221.0 x 50.0

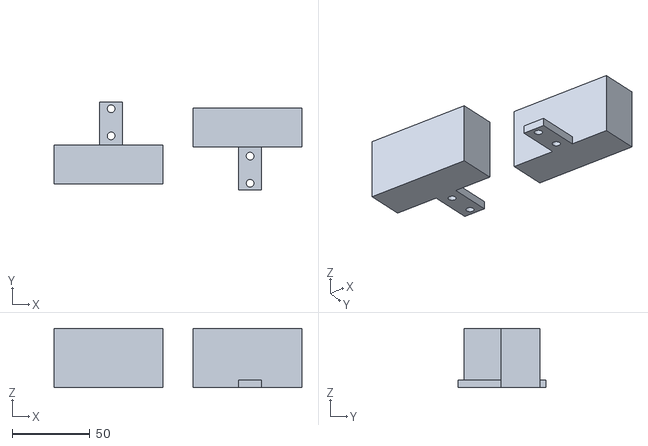
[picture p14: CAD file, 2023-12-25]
logistics_management_system_3d_printer_designs/motor_mounting_bracket.stl
160.0 x 57.0 x 38.2

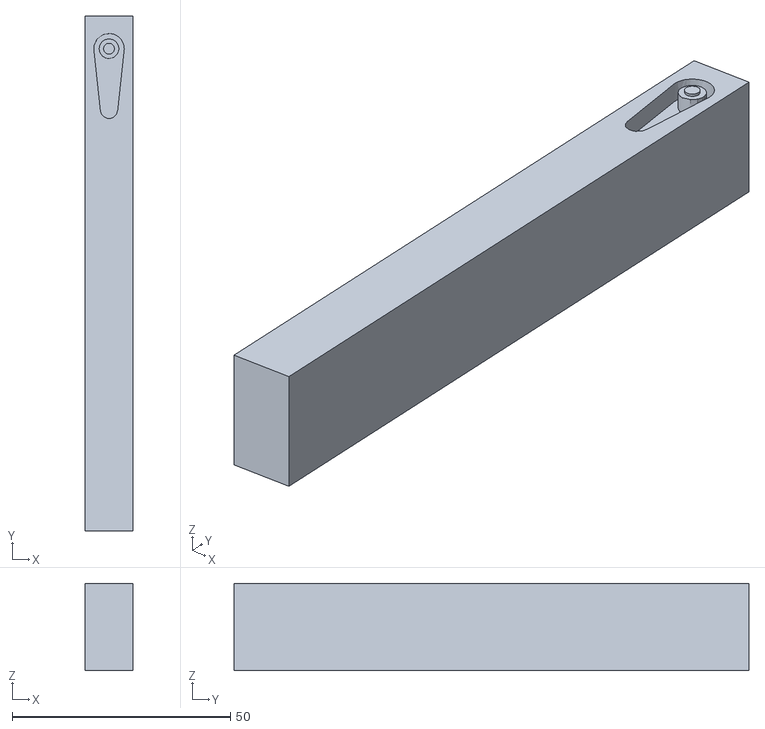
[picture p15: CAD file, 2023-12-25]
logistics_management_system_3d_printer_designs/adjustment_bar.stl
11.0 x 118.0 x 20.0

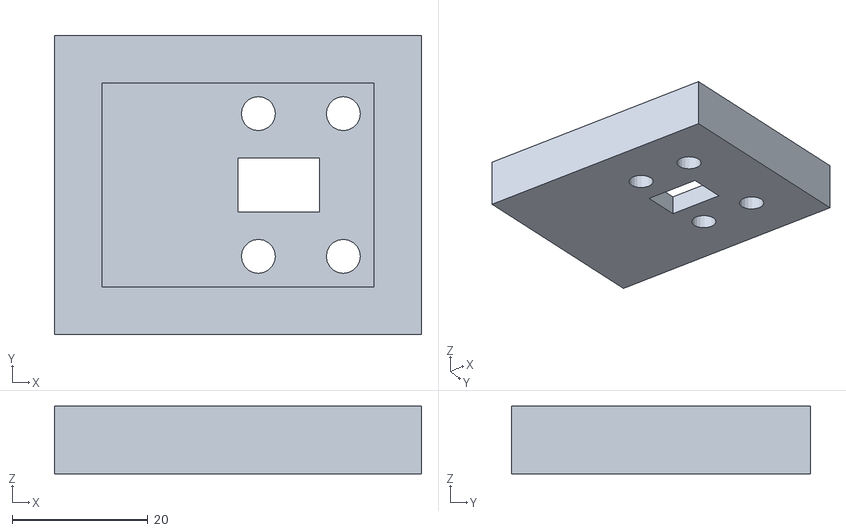
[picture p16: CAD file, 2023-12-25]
logistics_management_system_3d_printer_designs/camera_stand.stl
54.0 x 44.0 x 10.0

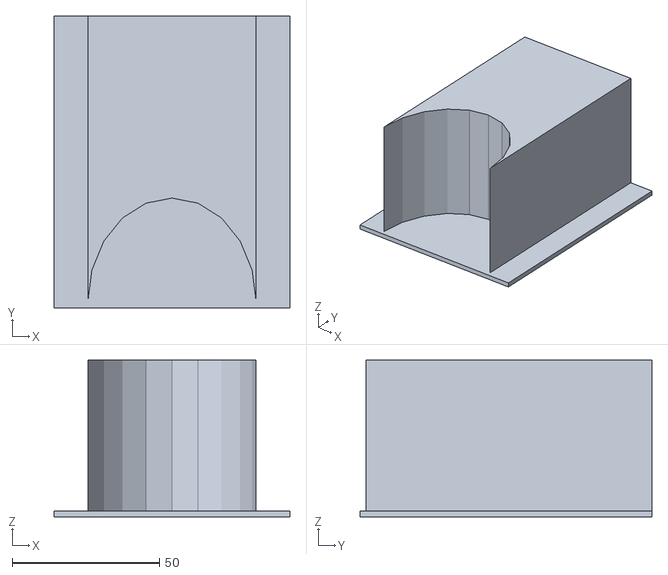
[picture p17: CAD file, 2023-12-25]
logistics_management_system_3d_printer_designs/conveyor_belt_3.stl
80.0 x 99.1 x 53.2

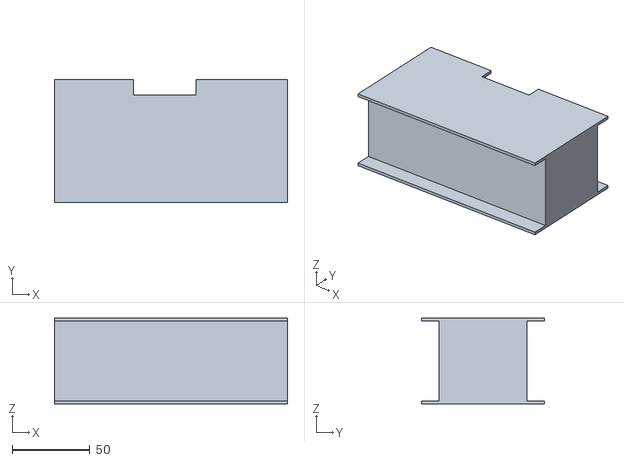
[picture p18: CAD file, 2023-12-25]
logistics_management_system_3d_printer_designs/conveyor_belt_2.stl
149.5 x 79.0 x 55.2

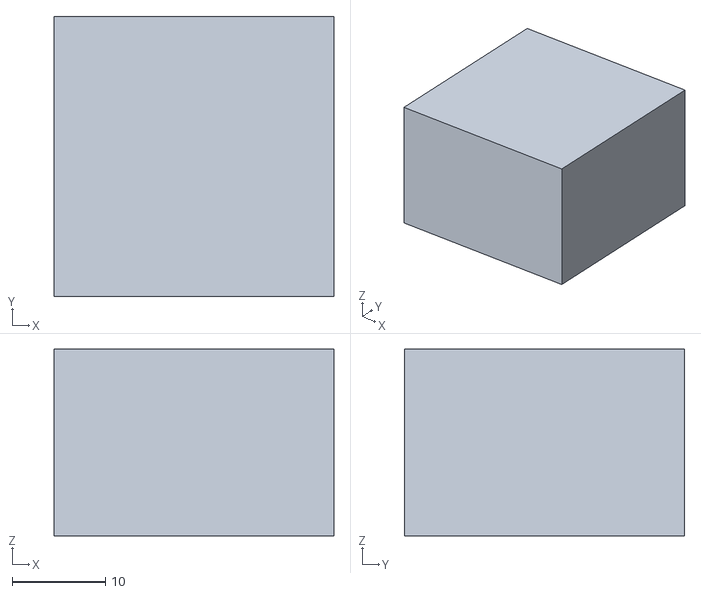
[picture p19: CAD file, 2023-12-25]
logistics_management_system_3d_printer_designs/logistics_object.stl
30.0 x 30.0 x 20.0

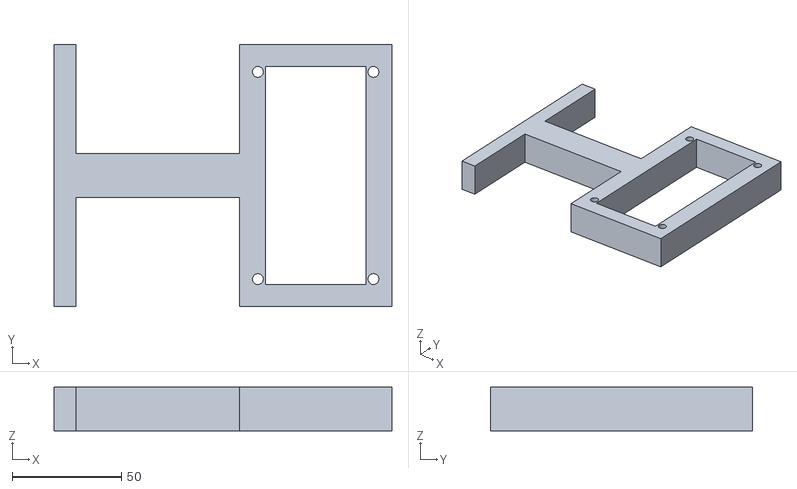
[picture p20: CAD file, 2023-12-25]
logistics_management_system_3d_printer_designs/lcd_display_stand.stl
155.0 x 120.0 x 20.0

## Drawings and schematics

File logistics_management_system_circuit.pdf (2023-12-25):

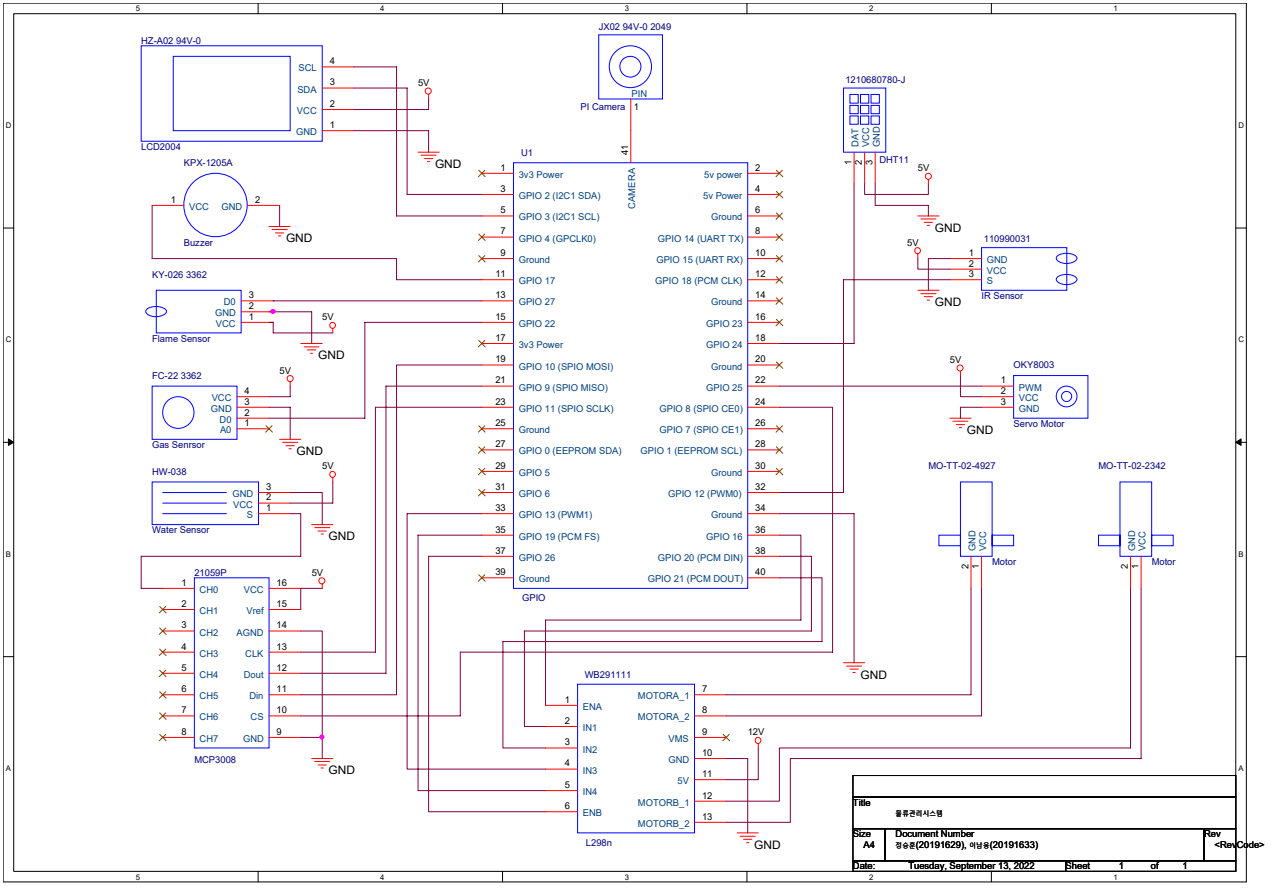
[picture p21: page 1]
GND; Title; Size; Document Number; Rev; Date:; Sheet; 정승훈; 이남웅 (20191629),; <RevCode>; 물류관리시스템; Tuesday, September 13, 2022; LCD2004; VCC; SDA; SCL; OKY8003; Servo Motor; PWM; Motor; 1 GND; MCP3008; Din; Dout; CLK; AGND; Vref 15; PI Camera; PIN; ENA; ENB; MOTORA_1; MOTORA_2; VMS; MOTORB_1 12; MOTORB_2 13; IR Sensor; Flame Sensor; DHT11; DAT; KPX-1205A; Buzzer; Water Sensor; 1 VCC; GPIO; 3v3 Power; GPIO 2 (I2C1 SDA); GPIO 3 (I2C1 SCL); GPIO 4 (GPCLK0); 5v power; 5v Power; Ground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

GPIO 14 (UART TX)

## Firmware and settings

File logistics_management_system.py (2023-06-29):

import sys
import time
import RPi.GPIO as GPIO
import cv2
import pyzbar.pyzbar as pyzbar
import pigpio
import dht11
import spidev
from multiprocessing import Process
from RPi_I2C_LCD_driver import RPi_I2C_driver

GPIO.setmode(GPIO.BCM)
GPIO.setwarnings(False)
GPIO.cleanup()

cap = cv2.VideoCapture(0)

motor1_pin = (16, 20, 21)                 #ENA, IN1, IN2
motor2_pin = (13, 19, 26)                    #IN3, IN4, ENB
GPIO.setup(motor1_pin, GPIO.OUT)
GPIO.setup(motor2_pin, GPIO.OUT)
pwm1 = GPIO.PWM(motor1_pin[0], 50)
pwm2 = GPIO.PWM(motor2_pin[2], 50)
pwm1.start(50)
pwm2.start(50)
motor_spe, motor_dur = 0, 0
motor_state = 0

ir_pin = (12)
GPIO.setup(ir_pin, GPIO.IN)
ir_sta = 0

pi = pigpio.pi()

buzzer_pin = (17)
GPIO.setup(buzzer_pin, GPIO.OUT)
GPIO.output(buzzer_pin, False)

lcd = RPi_I2C_driver.lcd(0x27)
lcd.clear()
lcd_celsius_symbol = (0b00111, 0b00101, 0b00111, 0b00000, 0b00000, 0b00000, 0b00000, 0b00000)
crisis_string = ['', '', '', '']
state_temp = 0

dht11_pin = dht11.DHT11(pin = 18)
dht11 = dht11_pin.read()
dht11_state = [0, 0]

spi = spidev.SpiDev()
spi.open(0, 0)
spi.max_speed_hz = 250000
spi_channel = (0)
flood_state = ''

flame_pin = (27)
GPIO.setup(flame_pin, GPIO.IN)
flame_state = 0

gas_pin = (22)
GPIO.setup(gas_pin, GPIO.IN)
gas_state = 0

object_list = ('1001', '1002', '1003')
object_num = [0, 0, 0, 0]                 #All Storage, First Storage, Second Storage, Third Storage
iden_obj = 0
object_order = []
print_text = ''

def motor_start(motor_spe):
    #모터 작동 함수
    pwm1.ChangeDutyCycle(motor_spe)
    pwm2.ChangeDutyCycle(motor_spe)
    GPIO.output(motor1_pin[1], True)
    GPIO.output(motor1_pin[2], False)
    GPIO.output(motor2_pin[0], True)
    GPIO.output(motor2_pin[1], False)
    
def motor_stop(motor_dur):
    #모터 정지 함수
    time.sleep(motor_dur)
    pwm1.ChangeDutyCycle(0)
    pwm2.ChangeDutyCycle(0)
  
def buzzer(buzzer_num):
    #경고음 알림 함수
    for i in range(0, buzzer_num):
        GPIO.output(buzzer_pin, True)
        time.sleep(0.0625)
        GPIO.output(buzzer_pin, False)
        time.sleep(0.0625)
  
def flood():
    #Water Sensor 작동에 필요한 함수
    assert 0 <= spi_channel <= 0
        
    if spi_channel:
        cbyte = 0b11000000
    else:
        cbyte = 0b10000000

    r = spi.xfer2([1, cbyte, 0])
    
    return ((r[1] & 31) << 6) + (r[2] >> 2)

def motor_action(motor_state, iden_obj):
    #모터, 서보모터 작동 함수
    if motor_state == 1:
        motor_start(35)
    if not(GPIO.input(ir_pin)):
        if iden_obj == 1001:
            pi.set_servo_pulsewidth(25, 1600)    #1번 창고
        elif iden_obj == 1002:
            pi.set_servo_pulsewidth(25, 1250)    #2번 창고
        elif iden_obj == 1003:
            pi.set_servo_pulsewidth(25, 1000)    #3번 창고
        motor_start(80)
        motor_stop(3)
        pi.set_servo_pulsewidth(25, 1000)
        motor_state = 0
        return motor_state

def state_print(state_mode, crisis_string):
    #LCD 상태 출력 함수
    global dht11, dht11_state
    print("--------------------------------------------------")
    print("%s\n%s\n%s\n%s" % (crisis_string[0], crisis_string[1], crisis_string[2], crisis_string[3]))
    print(motor_state)
    if state_mode < 3:
        for i in range(0, 2):
            lcd.setCursor(0,i)
            lcd.print(crisis_string[i])
        for i in range(2, 3):
            lcd.setCursor(4,i)
            lcd.print(crisis_string[i])
        lcd.setCursor(4,3)
        lcd.print("Tem: %-3.1f" % dht11_state[0])
        lcd.createChar(0, lcd_celsius_symbol)
        lcd.setCursor(13,3)
        lcd.write(0)
        lcd.setCursor(14,3)
        lcd.print("C Hum: %d%%" % dht11_state[1])
            
    else:
        for i in range(0, 2):
            lcd.setCursor(0,i)
            lcd.print(crisis_string[i])
        for i in range(2, 4):
            lcd.setCursor(4,i)
            lcd.print(crisis_string[i])
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
